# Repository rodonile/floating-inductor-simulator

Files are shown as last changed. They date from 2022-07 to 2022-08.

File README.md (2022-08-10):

# floating-inductor-simulator
PCB design (KiCAD) of a floating inductor simulator circuit, based on the [Grueningen Synthetic Inductor Circuit](https://ieeexplore.ieee.org/document/1457733). The inductance can be changed via the trim potentiometer (RV1). The circuit with the selected components can be used to simulate inductors up to 80H. 

Formula for determining the inductance value of the circuit:

        L = R2^2 * RV1 * C4 / R7,   given R2 = R3 = R4

The desired value range of the inductance can be tweaked by changing the resistors/caps/pots values. For example, with the values on the schematic below and with a 10kOhm RV1 trim potentiometer we are able to simulate inductances ranging from 20mH to 7.7H. With a 100kOhm RV1 potentiometer the circuit can simulate inductances up to 80H.

The frequency operation range of the circuit spans from ~100Hz to ~10kHz. For signals near and outside this range the circuits starts being unstable.

The RV2 potentiometer is a series resistor that can be used to adjust the Q-factor of the circuit but has no influence on the inductance value.

## Schematics


## Layout and 3D view

Kicad project files are available in the [kicad](./kicad) folder.

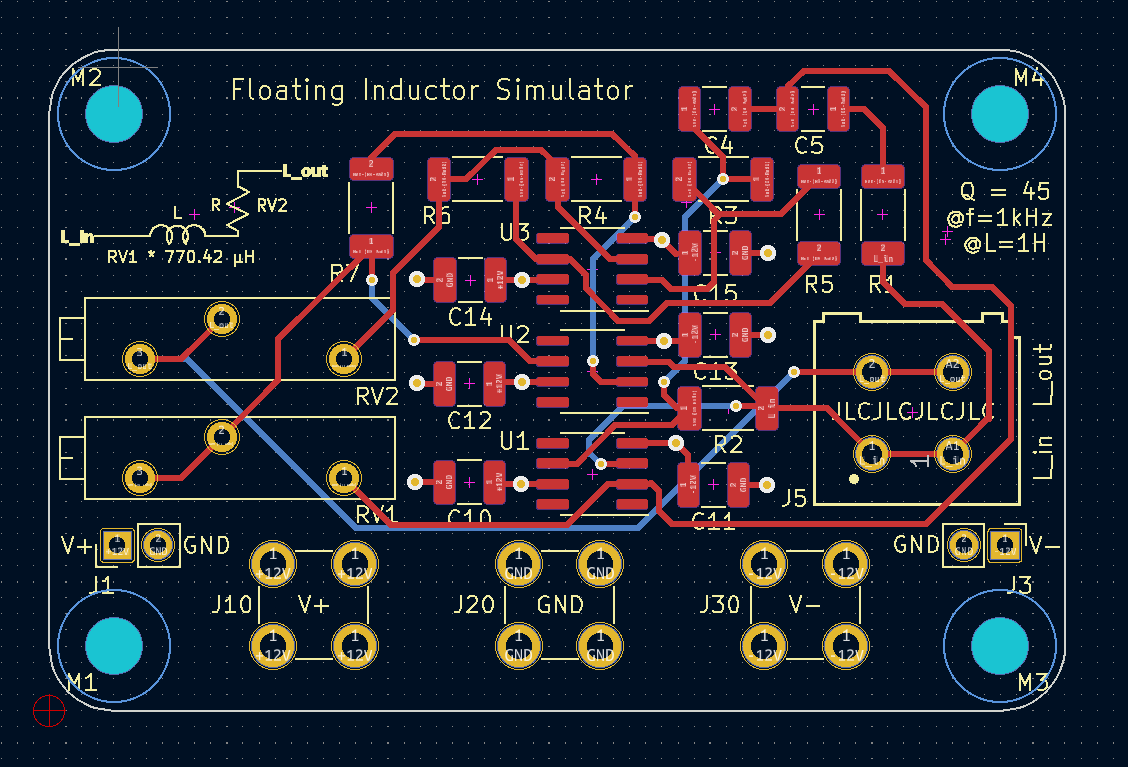
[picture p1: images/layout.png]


3D view TOP                |  3D view BOTTOM
:-------------------------:|:-------------------------:
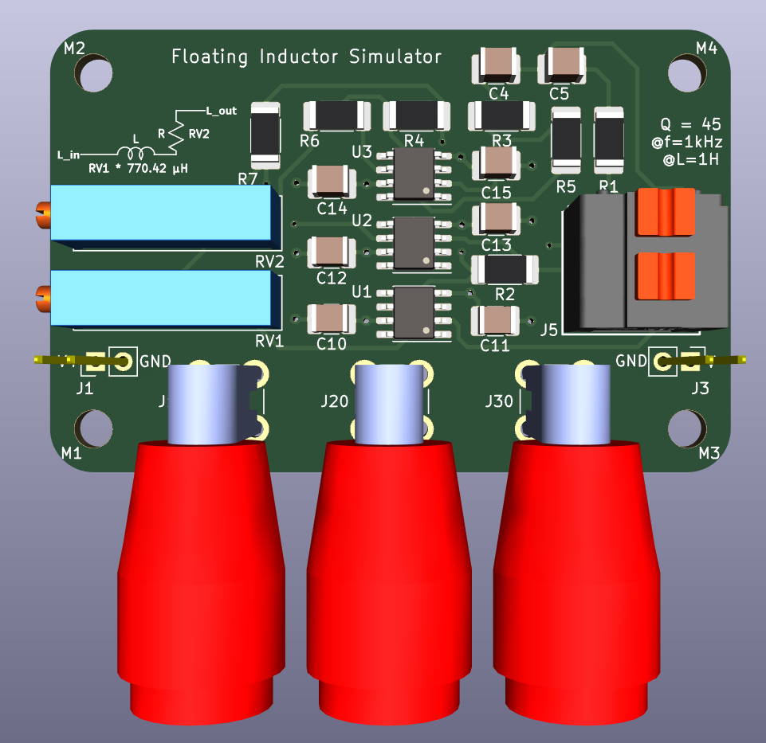
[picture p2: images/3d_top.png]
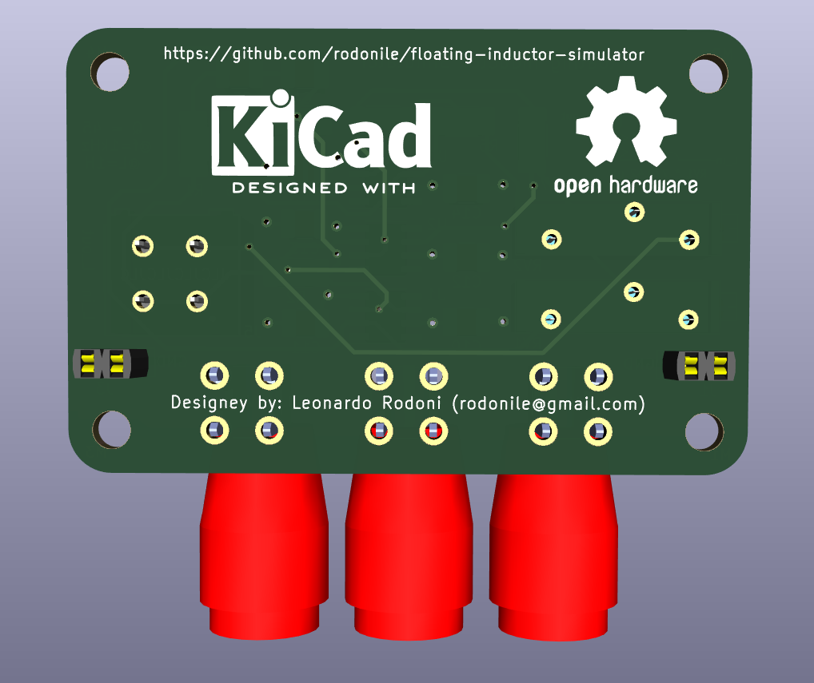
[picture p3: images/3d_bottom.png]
  |  

## Bill of materials (BOM)
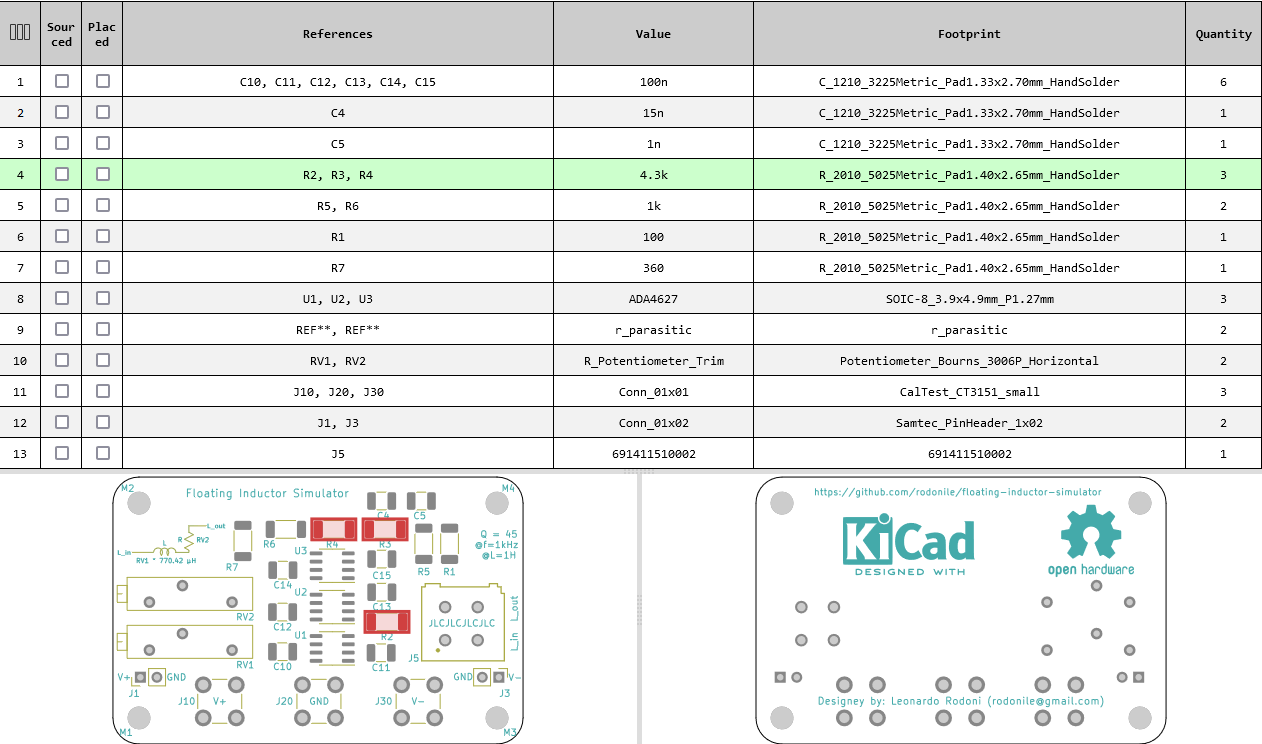
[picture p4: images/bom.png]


The bill of material is also available in the [ibom.html](https://raw.githubusercontent.com/rodonile/floating-inductor-simulator/main/ibom.html) file (interactive html format, to be opened with a web browser). The components I used to build the circuit are available as a [csv file](components-digikey.csv) (they were ordered from Digikey).

## Gerbers
Gerber files are available in [releases](https://github.com/rodonile/floating-inductor-simulator/releases). The board is a 4-layer PCB. Designed with JSCPCB design rules.

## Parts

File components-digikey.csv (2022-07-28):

Index | Customer Reference | Attrition % | Requested Quantity 1 | Pack Quantity 1 | Pack Type 1 | Digi-Key Part Number 1 | Unit Price 1 | Extended Price 1 | Minimum Order Quantity 1 | Manufacturer Part Number | Manufacturer Name | Description
1 | 100nF - C10, C11, C12, C13, C14, C15 |  | 6 | 6 | Cut Tape (CT) | 399-C1210C104K5RAC7210CT-ND | 0.30000 | Fr. 1.80 | 1 | C1210C104K5RAC7210 | KEMET | CAP CER 0.1UF 50V X7R 1210
2 | 15nF - C4 |  | 1 | 1 | Cut Tape (CT) | 399-15598-1-ND | 0.53000 | Fr. 0.53 | 1 | C1210C153K1RAC7800 | KEMET | CAP CER 0.015UF 100V X7R 1210
3 | 1nF - C5 |  | 1 | 1 | Cut Tape (CT) | 478-1602-1-ND | 0.33000 | Fr. 0.33 | 1 | 12101C102KAT2A | KYOCERA AVX | CAP CER 1000PF 100V X7R 1210
4 | 4.3k - R2, R3, R4 |  | 3 | 3 | Cut Tape (CT) | 541-4.3KWCT-ND | 0.31000 | Fr. 0.93 | 1 | CRCW20104K30JNEF | Vishay Dale | RES SMD 4.3K OHM 5% 3/4W 2010
5 | 1k - R5, R6 |  | 2 | 2 | Cut Tape (CT) | RMCF2010FT1K00CT-ND | 0.29000 | Fr. 0.58 | 1 | RMCF2010FT1K00 | Stackpole Electronics Inc | RES 1K OHM 1% 3/4W 2010
6 | 100 - R1 |  | 1 | 1 | Cut Tape (CT) | RMCF2010JT100RCT-ND | 0.21000 | Fr. 0.21 | 1 | RMCF2010JT100R | Stackpole Electronics Inc | RES 100 OHM 5% 3/4W 2010
7 | 360 - R7 |  | 1 | 1 | Cut Tape (CT) | RMCF2010JT360RCT-ND | 0.21000 | Fr. 0.21 | 1 | RMCF2010JT360R | Stackpole Electronics Inc | RES 360 OHM 5% 3/4W 2010
8 | U1, U2, U3 |  | 3 | 3 | Cut Tape (CT) | ADA4627-1ARZ-R7CT-ND | 9.35000 | Fr. 28.05 | 1 | ADA4627-1ARZ-R7 | Analog Devices Inc. | IC OPAMP JFET 1 CIRCUIT 8SOIC
9 | J10, J11 |  | 1 | 1 | Bulk | BKCT3151SP-2-ND | 2.18000 | Fr. 2.18 | 1 | CT3151SP-2 | Cal Test Electronics | CONN BANANA JACK SOLDER RED
10 | J20, J21 |  | 1 | 1 | Bulk | BKCT3151SP-9-ND | 2.18000 | Fr. 2.18 | 1 | CT3151SP-9 | Cal Test Electronics | CONN BANANA JACK SOLDER WHITE
11 | J30, J31 |  | 1 | 1 | Bulk | BKCT3151SP-0-ND | 2.18000 | Fr. 2.18 | 1 | CT3151SP-0 | Cal Test Electronics | CONN BANANA JACK SOLDER BLACK
12 | J1-J4 |  | 4 | 4 | Bulk | SAM1125-02-ND | 0.40000 | Fr. 1.60 | 1 | SSA-102-W-T | Samtec Inc. | CONN RCPT 2POS 0.1 TIN PCB
13 | J5 |  | 1 | 1 | Bulk | 732-691411510002-ND | 1.02000 | Fr. 1.02 | 1 | 691411510002 | Würth Elektronik | 5.08 MM TERMINAL BLOCK, HORIZONT
14 | RV2 |  | 1 | 1 | Tube | 3006P-7-502LF-ND | 2.04000 | Fr. 2.04 | 1 | 3006P-7-502LF | Bourns Inc. | TRIMMER 5K OHM 0.75W PC PIN
15 | RV1 |  | 1 | 1 | Tube | 3006P-7-103LF-ND | 2.04000 | Fr. 2.04 | 1 | 3006P-7-103LF | Bourns Inc. | TRIMMER 10K OHM 0.75W PC PIN

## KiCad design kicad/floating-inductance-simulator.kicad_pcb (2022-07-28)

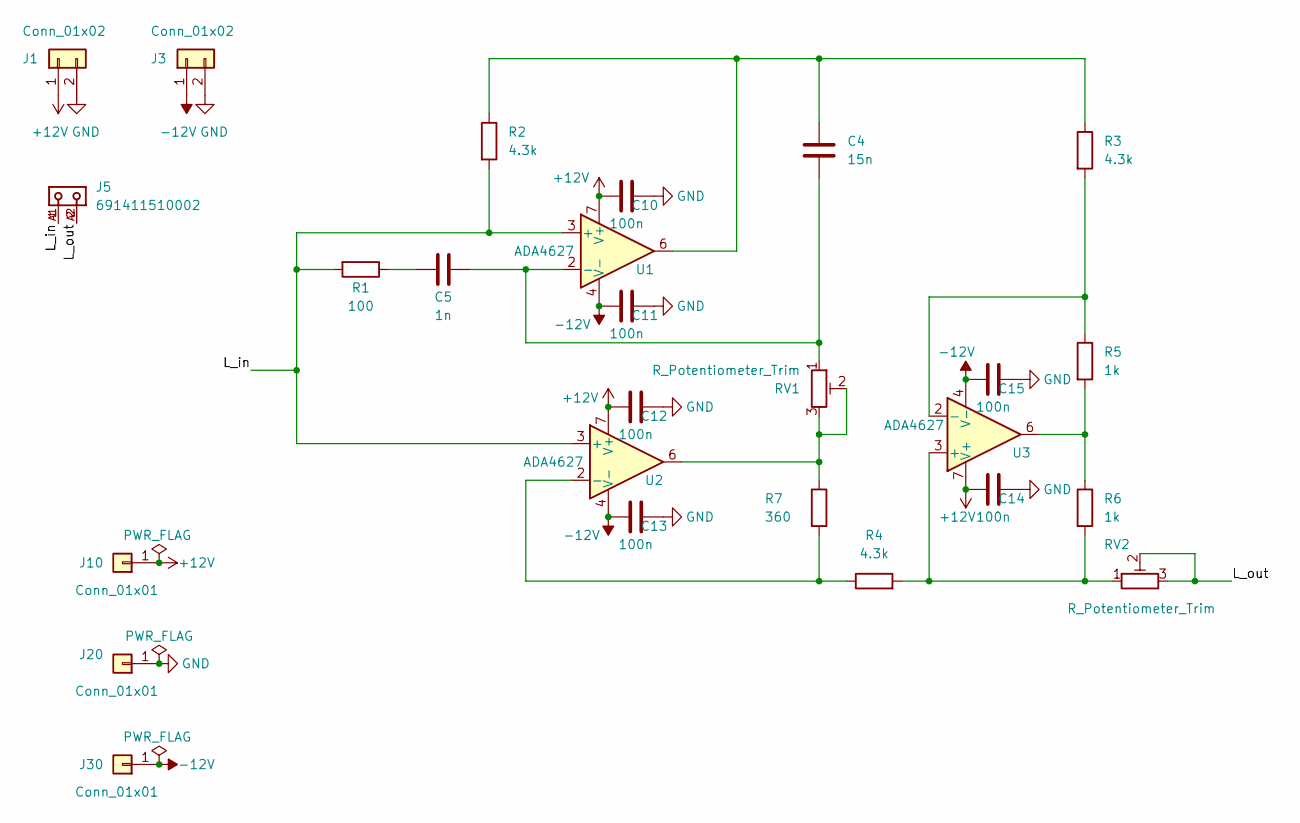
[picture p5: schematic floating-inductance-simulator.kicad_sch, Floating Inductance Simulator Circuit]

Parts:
C4: 15n; C_1210_3225Metric_Pad1.33x2.70mm_HandSolder
C5: 1n; C_1210_3225Metric_Pad1.33x2.70mm_HandSolder
C10, C11, C12, C13, C14, C15: 100n; C_1210_3225Metric_Pad1.33x2.70mm_HandSolder
J1, J3: Conn_01x02; Samtec_PinHeader_1x02
J5: 691411510002; PART-NUMBER 691411510002
J10, J20, J30: Conn_01x01; CalTest_CT3151_small
R1: 100; R_2010_5025Metric_Pad1.40x2.65mm_HandSolder
R2, R3, R4: 4.3k; R_2010_5025Metric_Pad1.40x2.65mm_HandSolder
R5, R6: 1k; R_2010_5025Metric_Pad1.40x2.65mm_HandSolder
R7: 360; R_2010_5025Metric_Pad1.40x2.65mm_HandSolder
RV1, RV2: R_Potentiometer_Trim; Potentiometer_Bourns_3006P_Horizontal
U1, U2, U3: ADA4627; SOIC-8_3.9x4.9mm_P1.27mm

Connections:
+12V: C10.1, C12.1, C14.1, J1.1, J10.1, U1.7 (V+), U2.7 (V+), U3.7 (V+)
-12V: C11.1, C13.1, C15.1, J3.1, J30.1, U1.4 (V-), U2.4 (V-), U3.4 (V-)
/L_in: J5.1, J5.A1, R1.2, R2.2, U1.3 (+), U2.3 (+)
/L_out: J5.2, J5.A2, RV2.2, RV2.3
GND: C10.2, C11.2, C12.2, C13.2, C14.2, C15.2, J1.2, J3.2, J20.1
unnamed: C4.1, R2.1, R3.1, U1.6
unnamed: C4.2, C5.2, RV1.1, U1.2 (-)
unnamed: C5.1, R1.1
unnamed: R3.2, R5.1, U3.2 (-)
unnamed: R4.1, R7.2, U2.2 (-)
unnamed: R4.2, R6.2, RV2.1, U3.3 (+)
unnamed: R5.2, R6.1, U3.6
unnamed: R7.1, RV1.2, RV1.3, U2.6

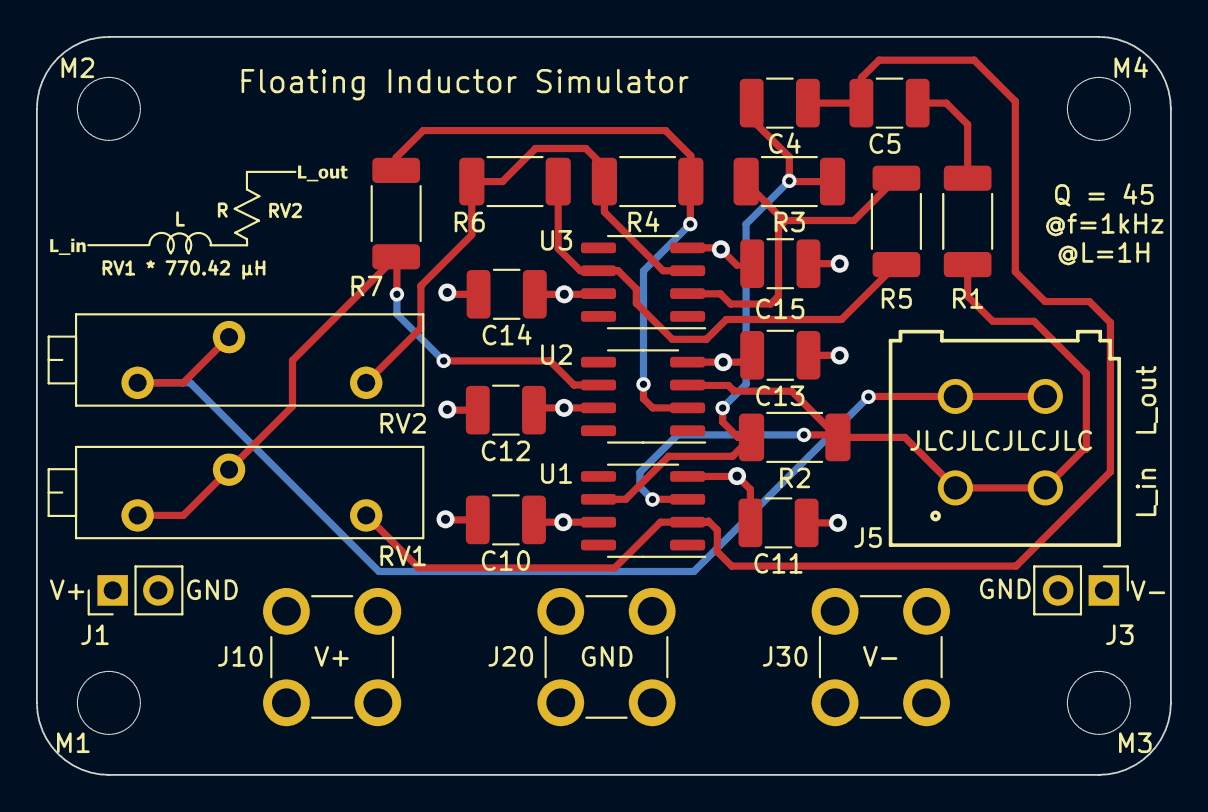
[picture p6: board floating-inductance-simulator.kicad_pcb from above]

Board: 4 copper layers, 63.0 x 41.0 mm, 30 parts (0 on the bottom side), 13 nets.

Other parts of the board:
M1, M2, M3, M4: MountingHole_3.5mm

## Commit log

2022-07-28 uploade BOM
2022-07-28 upload png bom
2022-07-28 upload digikey component list
    [components-digikey.csv]
2022-07-28 add kicad project and libraries
    [floating-inductance-simulator.kicad_pcb, floating-inductance-simulator.kicad_sch]
